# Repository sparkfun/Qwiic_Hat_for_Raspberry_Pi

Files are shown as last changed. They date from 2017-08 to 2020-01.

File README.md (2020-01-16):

SparkFun Qwiic pHAT v2.0 for Raspberry Pi
========================================

SparkFun Qwiic pHAT v2.0 for Raspberry Pi (https://www.sparkfun.com/products/15945)

[*SparkFun Qwiic pHAT for Raspberry Pi*](https://www.sparkfun.com/products/15945)

This is a board that connects the I<sup>2</sup>C bus on the Raspberry Pi to 4 Qwiic connectors.

Repository Contents
-------------------

* **/Hardware** - Eagle design files (.brd, .sch)
* **/Production** - Production panel files (.brd)

Documentation
--------------
* **[Hookup Guide](https://learn.sparkfun.com/tutorials/qwiic-phat-for-raspberry-pi-hookup-guide)** - Basic hookup guide for the SparkFun Qwiic pHAT for Raspberry Pi.

Product Versions
----------------
* [DEV-15945](https://www.sparkfun.com/products/15945)- Qwiic pHAT v2.0
* [DEV-15351](https://www.sparkfun.com/products/15351)- Qwiic pHAT v1.0
* [DEV-14459](https://www.sparkfun.com/products/14459) - Qwiic HAT SparkFun Reds Initial Release
* [DEV-14292](https://www.sparkfun.com/products/14292) - SparkX Version

License Information
-------------------

This product is _**open source**_! 

Please review the LICENSE.md file for license information. 

If you have any questions or concerns on licensing, please contact technical support on our [SparkFun forums](https://forum.sparkfun.com/viewforum.php?f=152).

Distributed as-is; no warranty is given.

- Your friends at SparkFun.

_<COLLABORATION CREDIT>_

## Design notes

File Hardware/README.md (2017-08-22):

SparkFun <PRODUCT NAME> Design Files
=====================================

The .sch and .brd files hare are Eagle CAD schematic and PCB design files from SparkFun Electronics.
A freeware version of Eagle can be found [here](http://www.cadsoftusa.com/download-eagle/freeware/).

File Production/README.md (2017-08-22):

SparkFun <PRODUCT NAME> Production Files
=========================================

These are the production files SparkFun uses for printing PCBs.

License Information
-------------------
This product is open source! 

The hardware is released under [Creative Commons ShareAlike 4.0 International](https://creativecommons.org/licenses/by-sa/4.0/).

Please use, reuse, and modify these files as you see fit. Please maintain attribution to SparkFun Electronics and release anything derivative under the same license.

Distributed as-is; no warranty is given.

- Your friends at SparkFun.

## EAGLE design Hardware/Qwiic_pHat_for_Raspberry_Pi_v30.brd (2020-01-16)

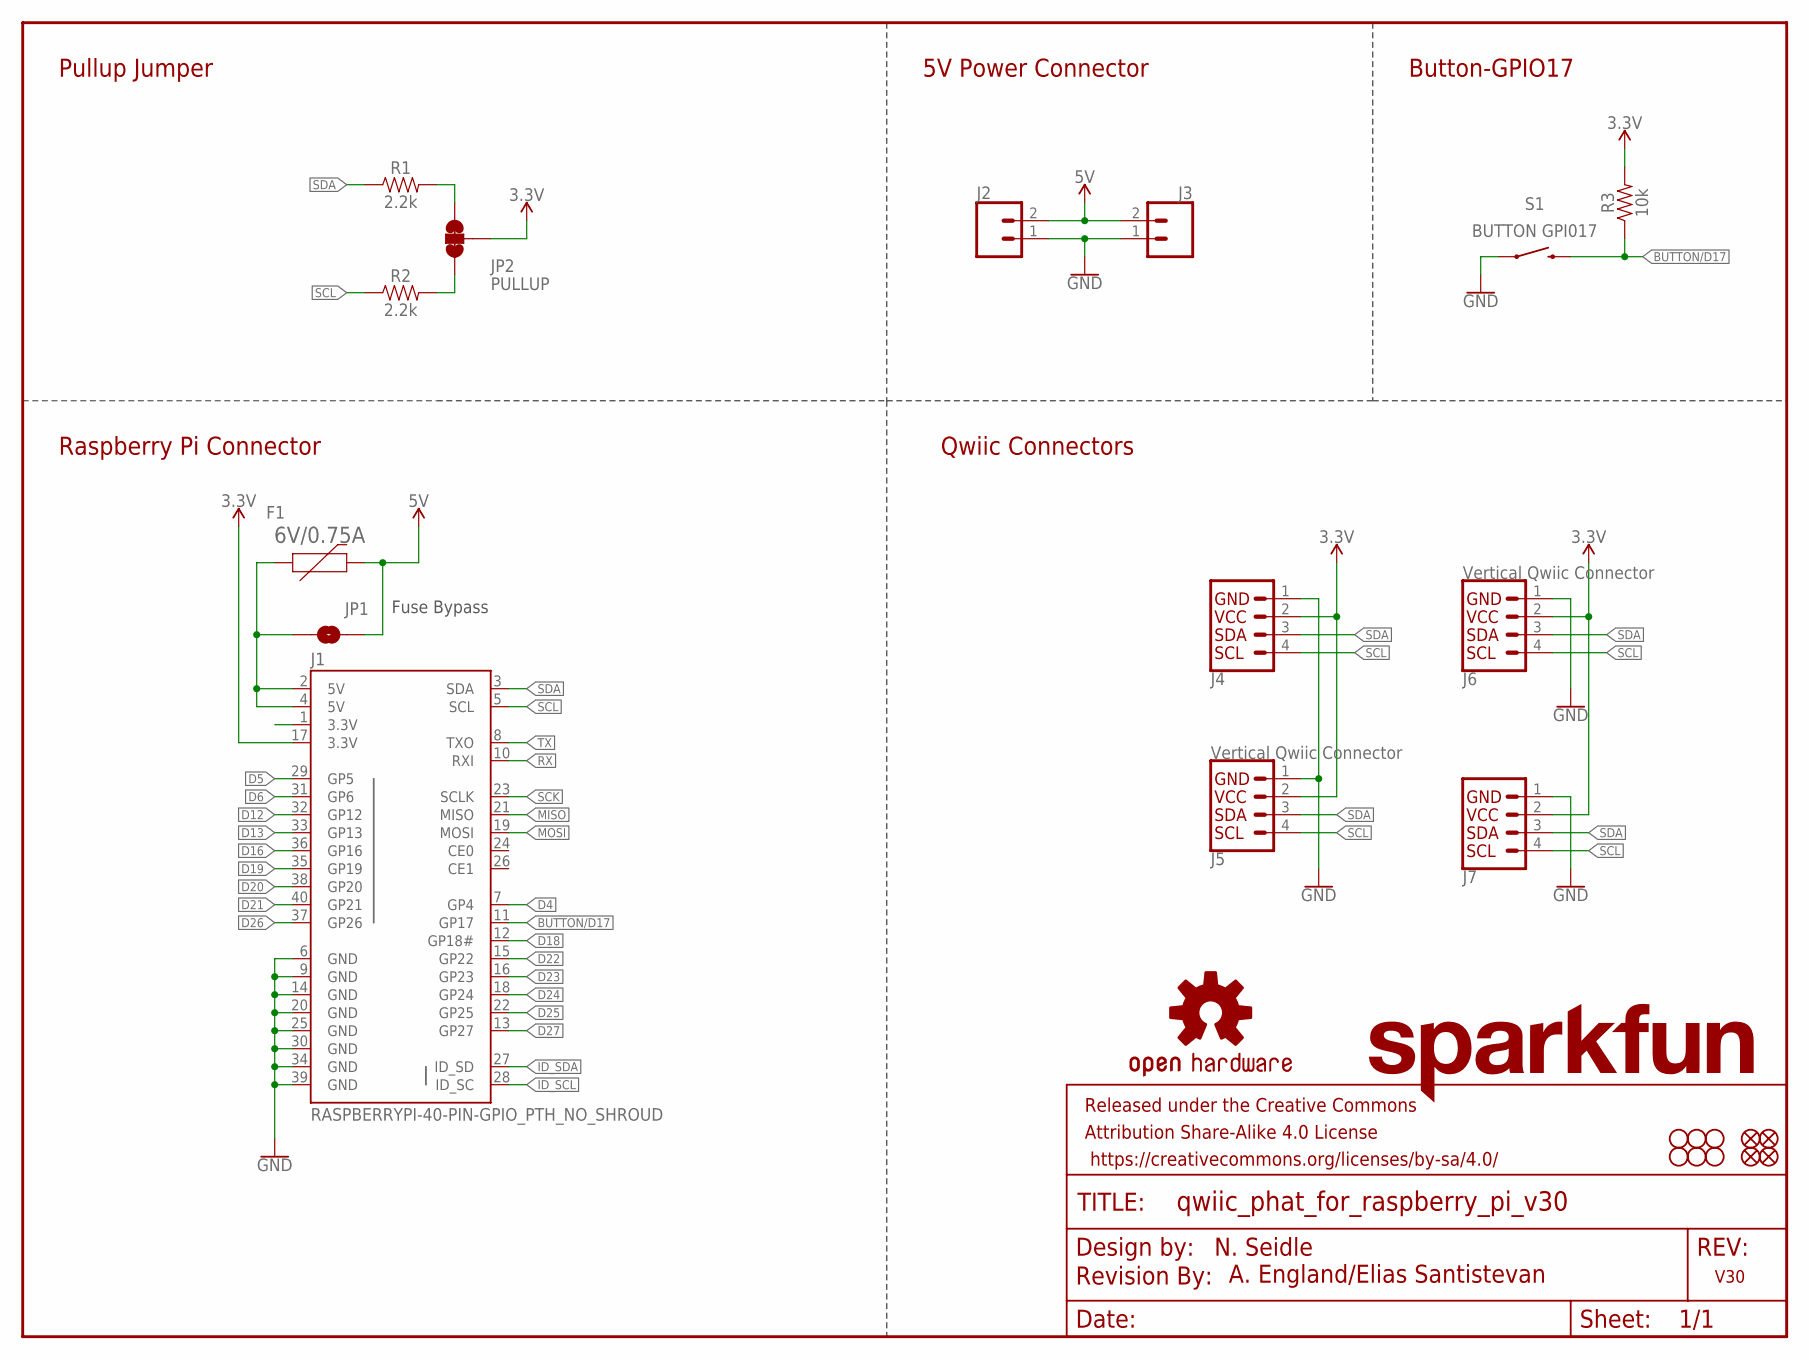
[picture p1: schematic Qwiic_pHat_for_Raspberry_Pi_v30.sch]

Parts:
F1: 6V/0.75A; 1206
FD1, FD2, FD3, FD4: FIDUCIAL1X2; FIDUCIAL-1X2
FRAME1: FRAME-LETTER; CREATIVE_COMMONS
H1, H2, H3, H4, H5, H6: STAND-OFFTIGHT; STAND-OFF-TIGHT
J1: RASPBERRYPI-40-PIN-GPIO_PTH_NO_SHROUD; 2X20
J2: CONN_023.5MM-NO_SILK; SCREWTERMINAL-3.5MM-2-NS
J3: CONN_023.5MM; SCREWTERMINAL-3.5MM-2
J4, J7: Qwiic Right Angle; JST04_1MM_RA
J5, J6: Vertical Qwiic Connector; JST04_1MM_VERT
JP1: JUMPER-SMT_2_NO_SILK; SMT-JUMPER_2_NO_SILK
JP2: PULLUP; SMT-JUMPER_3_2-NC_TRACE_NO-SILK
LOGO1: REVISION
LOGO2: OSHW-LOGOS; OSHW-LOGO-S
LOGO3: SFE_LOGO_NAME.1_INCH; SFE_LOGO_NAME_.1
R1, R2: 2.2k; 0603
R3: 10k; 0603
S1: BUTTON GPI017; TACTILE_SWITCH_SMD_5.2MM

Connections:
3.3V: J1.17 (3.3V), J4.2, J5.2, J6.2, J7.2, JP2.2, R3.2
5V: F1.2, J2.2, J3.2, JP1.2
BUTTON/D17: J1.11 (GP17), R3.1, S1.3 (2)
D4: J1.7 (GP4)
D5: J1.29 (GP5)
D6: J1.31 (GP6)
D12: J1.32 (GP12)
D13: J1.33 (GP13)
D16: J1.36 (GP16)
D18: J1.12 (GP18#)
D19: J1.35 (GP19)
D20: J1.38 (GP20)
D21: J1.40 (GP21)
D22: J1.15 (GP22)
D23: J1.16 (GP23)
D24: J1.18 (GP24)
D25: J1.22 (GP25)
D26: J1.37 (GP26)
D27: J1.13 (GP27)
GND: J1.6 (GND), J1.9 (GND), J1.14 (GND), J1.20 (GND), J1.25 (GND), J1.30 (GND), J1.34 (GND), J1.39 (GND), J2.1, J3.1, J4.1, J5.1, J6.1, J7.1, S1.1
ID_SCL: J1.28 (ID_SC)
ID_SDA: J1.27 (ID_SD)
MISO: J1.21 (MISO)
MOSI: J1.19 (MOSI)
unnamed: F1.1, J1.2 (5V), J1.4 (5V), JP1.1
unnamed: JP2.3, R1.2
unnamed: JP2.1, R2.2
RX: J1.10 (RXI)
SCK: J1.23 (SCLK)
SCL: J1.5 (SCL), J4.4, J5.4, J6.4, J7.4, R2.1
SDA: J1.3 (SDA), J4.3, J5.3, J6.3, J7.3, R1.1
TX: J1.8 (TXO)

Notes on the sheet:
N. Seidle
Raspberry Pi Connector
V30
Qwiic Connectors
A. England/Elias Santistevan
Pullup Jumper
5V Power Connector
Button-GPIO17
Fuse Bypass

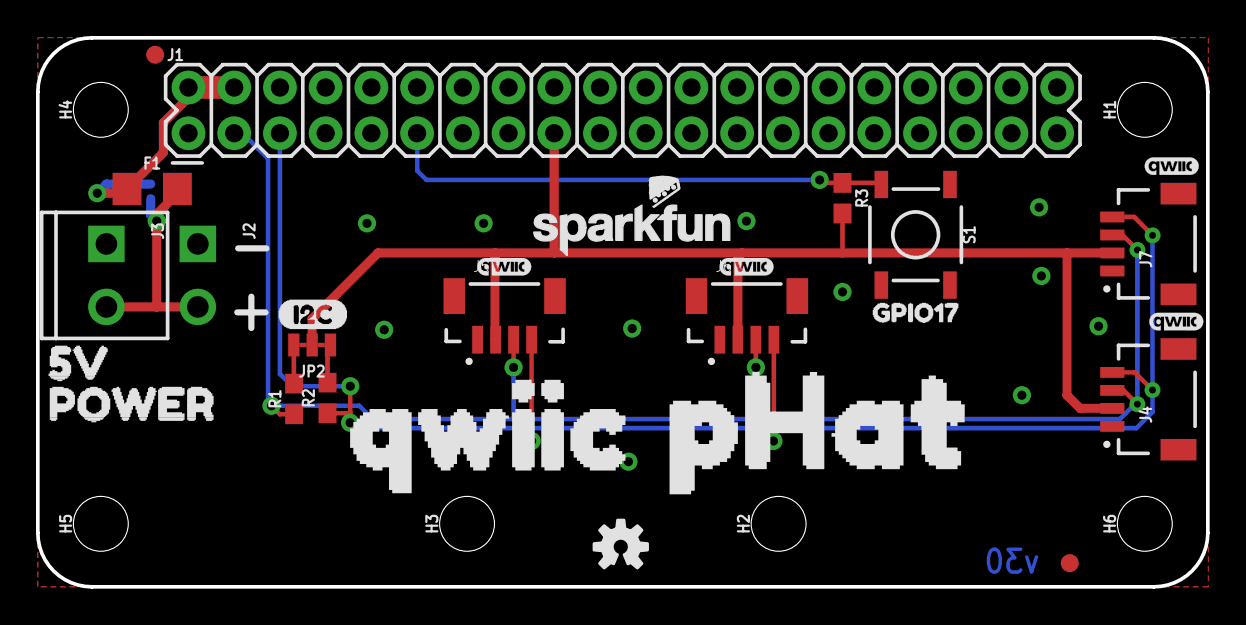
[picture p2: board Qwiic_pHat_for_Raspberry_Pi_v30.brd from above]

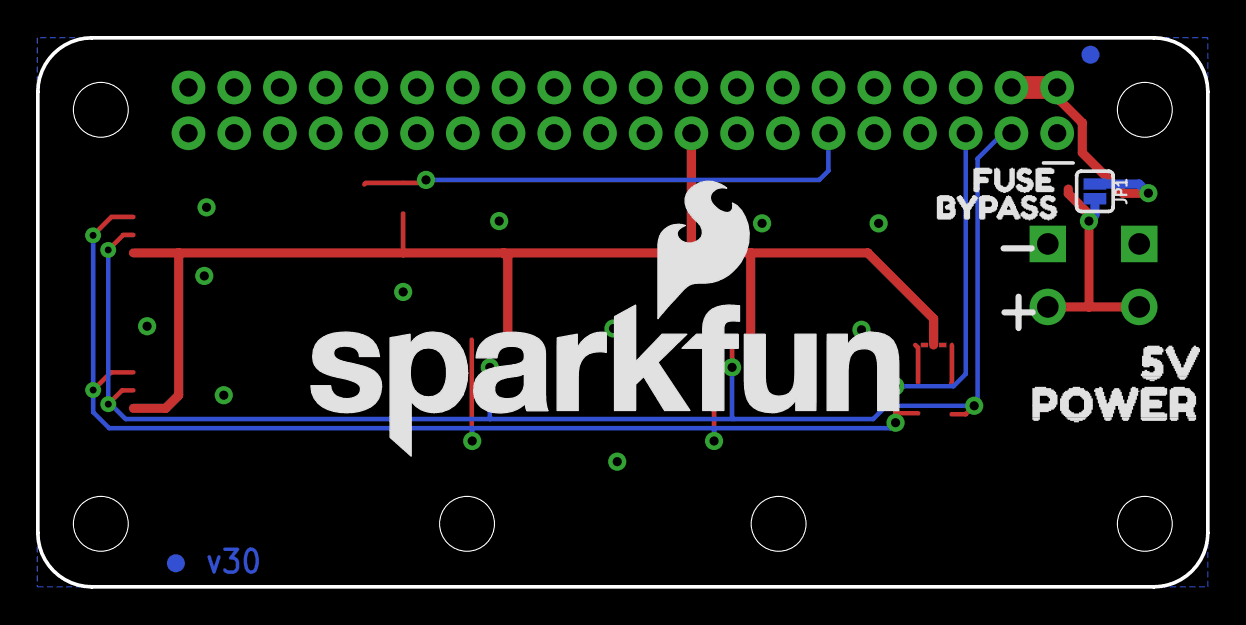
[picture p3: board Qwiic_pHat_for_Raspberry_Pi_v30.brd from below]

Board: 2 copper layers, 65.0 x 30.5 mm, 44 parts (8 on the bottom side), 9 nets.

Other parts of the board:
U$1: PIE_1F967#PNG
U$2: I2C-()
U$3: PHAT0
U$6: FUSE0
U$7: BYPASS1
U$8, U$11, U$16, U$17: QWIIC_3MM
U$9: GPIO173
U$10: SFE_LOGO_NAME_FLAME_.3
U$12, U$15: 5V0
U$13, U$14: POWER1
U$18: QWIIC0

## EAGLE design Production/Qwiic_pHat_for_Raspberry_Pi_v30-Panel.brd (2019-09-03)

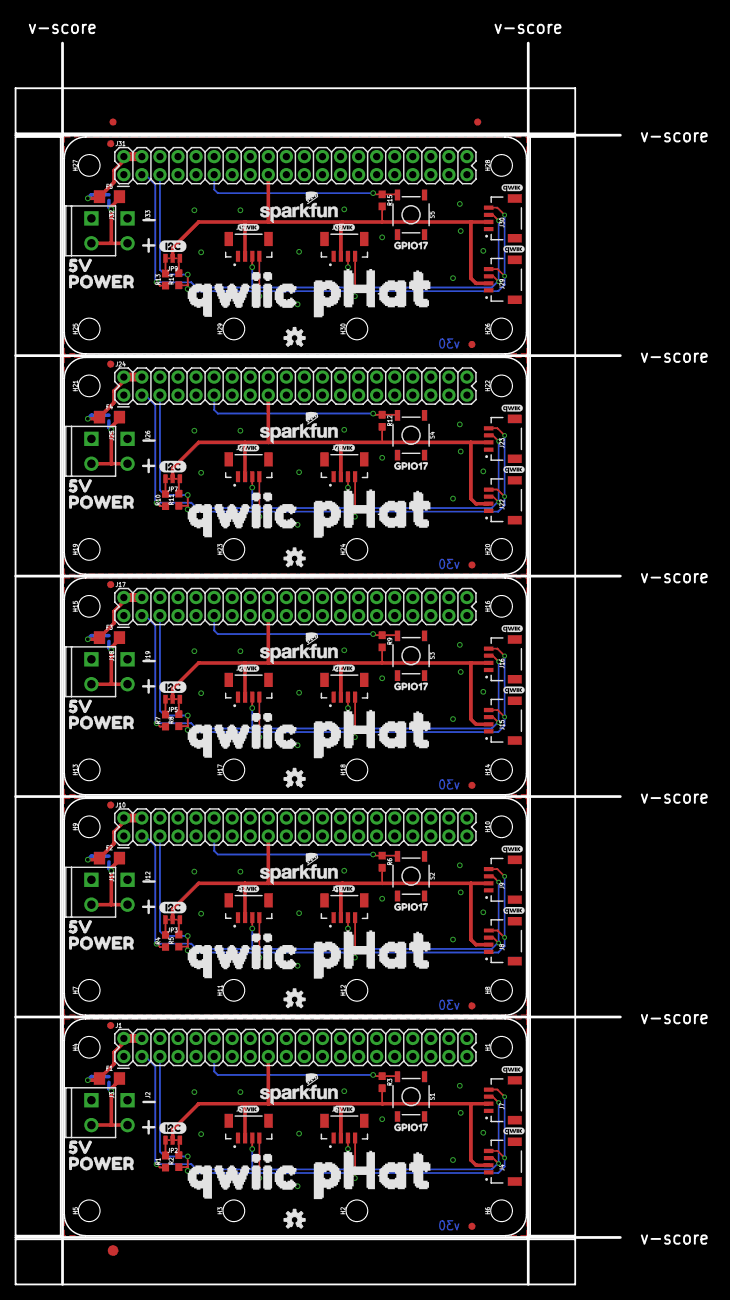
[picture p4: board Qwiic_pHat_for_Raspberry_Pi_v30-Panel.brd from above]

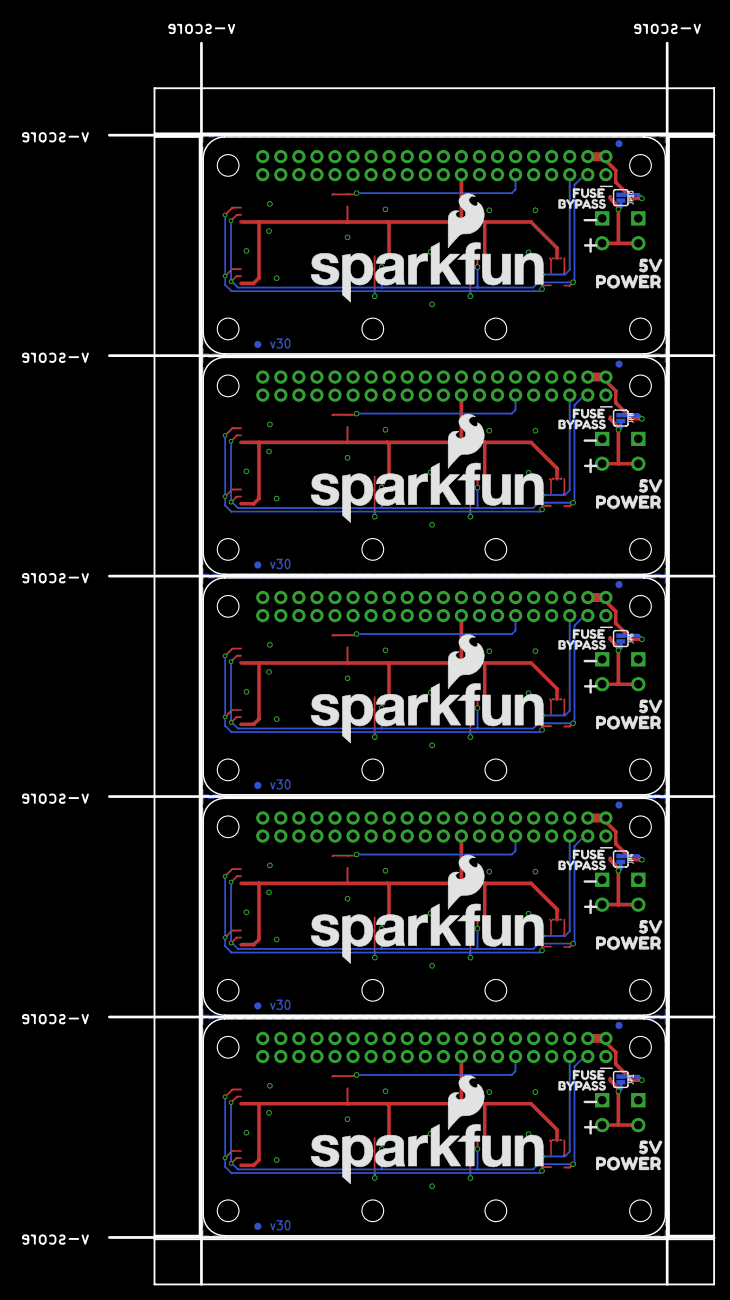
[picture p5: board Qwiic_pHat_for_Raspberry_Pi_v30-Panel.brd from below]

Board: 2 copper layers, 85.1 x 174.6 mm, 223 parts (40 on the bottom side), 45 nets.

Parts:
E$1, E$2: FIDUCIAL-1X2
E$3: FIDUCIAL-1.5X3
F1, F2, F3, F4, F5: 6V/0.75A; 1206
FD1, FD2, FD3, FD4, FD5, FD6, FD7, FD8, FD9, FD10, FD11, FD12, FD13, FD14, FD15, FD16, FD17, FD18, FD19, FD20: FIDUCIAL1X2; FIDUCIAL-1X2
FRAME1, FRAME2, FRAME3, FRAME4, FRAME5: FRAME-LETTER; CREATIVE_COMMONS
H1, H2, H3, H4, H5, H6, H7, H8, H9, H10, H11, H12, H13, H14, H15, H16, H17, H18, H19, H20, H21, H22, H23, H24, H25, H26, H27, H28, H29, H30: STAND-OFFTIGHT; STAND-OFF-TIGHT
J1, J10, J17, J24, J31: RASPBERRYPI-40-PIN-GPIO_PTH_NO_SHROUD; 2X20
J2, J12, J19, J26, J33: SCREWTERMINAL-3.5MM-2-NS
J3, J11, J18, J25, J32: SCREWTERMINAL-3.5MM-2
J4, J7, J8, J9, J15, J16, J22, J23, J29, J30: Qwiic Right Angle; JST04_1MM_RA
J5, J6, J13, J14, J20, J21, J27, J28, J34, J35: Vertical Qwiic Connector; JST04_1MM_VERT
JP1, JP4, JP6, JP8, JP10: JUMPER-SMT_2_NO_SILK; SMT-JUMPER_2_NO_SILK
JP2, JP3, JP5, JP7, JP9: PULLUP; SMT-JUMPER_3_2-NC_TRACE_NO-SILK
LOGO1, LOGO4, LOGO7, LOGO10, LOGO13: REVISION
LOGO2, LOGO5, LOGO8, LOGO11, LOGO14: OSHW-LOGOS; OSHW-LOGO-S
LOGO3, LOGO6, LOGO9, LOGO12, LOGO15: SFE_LOGO_NAME.1_INCH; SFE_LOGO_NAME_.1
R1, R2, R4, R5, R7, R8, R10, R11, R13, R14: 2.2k; 0603
R3, R6, R9, R12, R15: 10k; 0603
S1, S2, S3, S4, S5: BUTTON GPI017; TACTILE_SWITCH_SMD_5.2MM
U$1, U$31, U$47, U$63, U$79: PIE_1F967#PNG
U$2, U$5, U$34, U$50, U$66: I2C-()
U$3, U$4, U$33, U$49, U$65: PHAT0
U$6, U$20, U$36, U$52, U$68: FUSE0
U$7, U$21, U$37, U$53, U$69: BYPASS1
U$8, U$11, U$16, U$17, U$22, U$27, U$28, U$29, U$38, U$43, U$44, U$45, U$54, U$59, U$60, U$61, U$70, U$75, U$76, U$77: QWIIC_3MM
U$9, U$19, U$35, U$51, U$67: GPIO173
U$10, U$32, U$48, U$64, U$80: SFE_LOGO_NAME_FLAME_.3
U$12, U$15, U$23, U$26, U$39, U$42, U$55, U$58, U$71, U$74: 5V0
U$13, U$14, U$24, U$25, U$40, U$41, U$56, U$57, U$72, U$73: POWER1
U$18, U$30, U$46, U$62, U$78: QWIIC0

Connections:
3.3V: J1.17, J4.2, J5.2, J6.2, J7.2, JP2.2, R3.2
3.3V1: J8.2, J9.2, J10.17, J13.2, J14.2, JP3.2, R6.2
3.3V2: J15.2, J16.2, J17.17, J20.2, J21.2, JP5.2, R9.2
3.3V3: J22.2, J23.2, J24.17, J27.2, J28.2, JP7.2, R12.2
3.3V4: J29.2, J30.2, J31.17, J34.2, J35.2, JP9.2, R15.2
5V: F1.2, J2.2, J3.2, JP1.2
5V1: F2.2, J11.2, J12.2, JP4.2
5V2: F3.2, J18.2, J19.2, JP6.2
5V3: F4.2, J25.2, J26.2, JP8.2
5V4: F5.2, J32.2, J33.2, JP10.2
BUTTON/D1: J10.11, R6.1, S2.3
BUTTON/D2: J17.11, R9.1, S3.3
BUTTON/D3: J24.11, R12.1, S4.3
BUTTON/D4: J31.11, R15.1, S5.3
BUTTON/D17: J1.11, R3.1, S1.3
GND: J1.6, J1.9, J1.14, J1.20, J1.25, J1.30, J1.34, J1.39, J2.1, J3.1, J4.1, J5.1, J6.1, J7.1, S1.1
GND1: J8.1, J9.1, J10.6, J10.9, J10.14, J10.20, J10.25, J10.30, J10.34, J10.39, J11.1, J12.1, J13.1, J14.1, S2.1
GND2: J15.1, J16.1, J17.6, J17.9, J17.14, J17.20, J17.25, J17.30, J17.34, J17.39, J18.1, J19.1, J20.1, J21.1, S3.1
GND3: J22.1, J23.1, J24.6, J24.9, J24.14, J24.20, J24.25, J24.30, J24.34, J24.39, J25.1, J26.1, J27.1, J28.1, S4.1
GND4: J29.1, J30.1, J31.6, J31.9, J31.14, J31.20, J31.25, J31.30, J31.34, J31.39, J32.1, J33.1, J34.1, J35.1, S5.1
unnamed: F1.1, J1.2, J1.4, JP1.1
unnamed: JP2.3, R1.2
unnamed: JP2.1, R2.2
unnamed: JP3.3, R4.2
unnamed: JP3.1, R5.2
unnamed: F2.1, J10.2, J10.4, JP4.1
unnamed: JP5.3, R7.2
unnamed: JP5.1, R8.2
unnamed: F3.1, J17.2, J17.4, JP6.1
unnamed: JP7.3, R10.2
unnamed: JP7.1, R11.2
unnamed: F4.1, J24.2, J24.4, JP8.1
unnamed: JP9.3, R13.2
unnamed: JP9.1, R14.2
unnamed: F5.1, J31.2, J31.4, JP10.1
SCL: J1.5, J4.4, J5.4, J6.4, J7.4, R2.1
SCL1: J8.4, J9.4, J10.5, J13.4, J14.4, R5.1
SCL2: J15.4, J16.4, J17.5, J20.4, J21.4, R8.1
SCL3: J22.4, J23.4, J24.5, J27.4, J28.4, R11.1
SCL4: J29.4, J30.4, J31.5, J34.4, J35.4, R14.1
SDA: J1.3, J4.3, J5.3, J6.3, J7.3, R1.1
SDA1: J8.3, J9.3, J10.3, J13.3, J14.3, R4.1
SDA2: J15.3, J16.3, J17.3, J20.3, J21.3, R7.1
SDA3: J22.3, J23.3, J24.3, J27.3, J28.3, R10.1
SDA4: J29.3, J30.3, J31.3, J34.3, J35.3, R13.1

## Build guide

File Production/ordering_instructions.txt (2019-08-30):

panel size, 79x169mm
PCB thickness, 1.6mm
number of layers, 2
soldermask color, Red
silkscreen color, White
oz copper, 1oz
finish, HASL lead free
stencils, top+bottom
pcs per panel, 5
min trace width, 0.254000mm / 0.010000in
min drill size, 0.381000mm / 0.015000in

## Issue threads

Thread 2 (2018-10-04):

Consider I2C Pullups

nseidle, 2018-10-04:
We may want to add 2.2k pull ups with a I2C cut away jumper on the next rev.

edspark, 2019-04-26:
Each of our daughter boards have pull ups, do you still think this is necessary still? I suppose it wouldn't hurt....

edspark, 2019-04-26:
Added to v20

Closed 2019-04-26.

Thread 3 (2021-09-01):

Using pHAT on a different I2C bus

tamugo, 2021-09-01:
I'm working on a project where I am making use of a BME680 and IMU 20948 connected to a Raspberry Pi Zero using the Qwiic pHAT v2.0. I also have a battery pack that connects to the RPi the gpio pins. The pins on the battery's distribution board are connected to the first I2C bus, and so I want to make a second I2C bus and have the BME680 and IMU-20948 route through the new bus, but when I do the second bus shows no active addresses. Is there a way to have them go through a new I2C bus?

Closed 2021-09-01.

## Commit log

2017-08-23 Engineering checklist changes
    [Board_Design_Checklist.xls, Board_Design_Checklist_Qwiic Shield for Raspberry Pi_V01.xls, Qwiic Shield for RaspberryPi.brd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]
2017-08-25 Post design review changes
    [Qwiic Shield for RaspberryPi.brd]
2017-09-28 post design review
    [Board_Design_Checklist_Qwiic Shield for Raspberry Pi_V01.xls, Qwiic Shield for RaspberryPi.brd, Qwiic Shield for RaspberryPi.sch]
2017-09-28 Updated PROD_ID of 2x20
    [Qwiic Shield for RaspberryPi.brd, Qwiic Shield for RaspberryPi.sch]
2019-05-21 Update File Names
    Update file names to be consistent with name and version
    [Qwiic_pHat_for_Raspberry_Pi_v20.brd, Qwiic_pHat_for_Raspberry_Pi_v20.sch]
2019-05-21 Undo renaming
    [Qwiic Shield for RaspberryPi.brd, Qwiic Shield for RaspberryPi.sch]
2019-07-19 Removes production old files from v30
    [13791-Qwiic Shield for RaspberryPi-panel.v10.brd, Qwiic Shield for RaspberryPi.brd, Qwiic Shield for RaspberryPi.sch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]
2019-07-19 Renames board files to v30 for clarity
    [Qwiic_pHat_for_Raspberry_Pi_v30.brd, Qwiic_pHat_for_Raspberry_Pi_v30.sch]
2019-07-19 Adds vertical Qwiic connectors to board
    [Qwiic_pHat_for_Raspberry_Pi_v30.brd, Qwiic_pHat_for_Raspberry_Pi_v30.sch]
2019-07-22 Updates vertical qwiic connector footprint, recenters vertical qwiic connector.
    [Qwiic_pHat_for_Raspberry_Pi_v30.brd, Qwiic_pHat_for_Raspberry_Pi_v30.sch]
2019-07-23 Changes button and 5V power labels to text only, changes button text to "button" with gpio number
    * Adds parallel 5V power through holes
    * moves + and - silk
    * moves button gpio pin to 17
    [Qwiic_pHat_for_Raspberry_Pi_v30.brd, Qwiic_pHat_for_Raspberry_Pi_v30.sch]
2019-07-23 Adds gerbers
    [Qwiic_pHat_for_Raspberry_Pi_v30.GBL, Qwiic_pHat_for_Raspberry_Pi_v30.GBO, Qwiic_pHat_for_Raspberry_Pi_v30.GBS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]
2019-07-24 Adjusts 5V Power silk, changes button name in schematic
    [Qwiic_pHat_for_Raspberry_Pi_v30.brd, Qwiic_pHat_for_Raspberry_Pi_v30.sch]
2019-08-27 Adds resettable 750mA fuse to 5V power line
    [Qwiic_pHat_for_Raspberry_Pi_v30.brd, Qwiic_pHat_for_Raspberry_Pi_v30.sch]
2019-08-27 Moves 5V screw terminal and pull up resistors away from each other
    [Qwiic_pHat_for_Raspberry_Pi_v30.brd]
2019-08-28 Updates the silk
    [Qwiic_pHat_for_Raspberry_Pi_v30.brd, Qwiic_pHat_for_Raspberry_Pi_v30.sch]
2019-08-29 Swaps power and ground on screw terminal, adjusts silk in various areas
    [Qwiic_pHat_for_Raspberry_Pi_v30.brd, Qwiic_pHat_for_Raspberry_Pi_v30.sch]
2019-08-30 Updates vertical qwiic connector footprint
    [Qwiic_pHat_for_Raspberry_Pi_v30.brd]
2019-08-30 Adds current production files
    [Qwiic_pHat_for_Raspberry_Pi_v30-Panel.GBL, Qwiic_pHat_for_Raspberry_Pi_v30-Panel.GBO, Qwiic_pHat_for_Raspberry_Pi_v30-Panel.GBS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]
2019-09-03 Fixes vertical qwiic connector polarity marker with updated package, removes Qwiic board reference on TDocu
    [Qwiic_pHat_for_Raspberry_Pi_v30.brd, Qwiic_pHat_for_Raspberry_Pi_v30.sch]
2019-09-03 Updates Vertical Qwiic connector to have value of "vertical qwiic connector"
    [Qwiic_pHat_for_Raspberry_Pi_v30.brd, Qwiic_pHat_for_Raspberry_Pi_v30.sch]
2019-09-03 Nudges via on SparkFun flame
    [Qwiic_pHat_for_Raspberry_Pi_v30.brd]
2019-09-03 Adds updated production panel
    [Qwiic_pHat_for_Raspberry_Pi_v30-Panel.GBL, Qwiic_pHat_for_Raspberry_Pi_v30-Panel.GBO, Qwiic_pHat_for_Raspberry_Pi_v30-Panel.GBS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]
2020-01-16 Update Qwiic_pHat_for_Raspberry_Pi_v30.brd
    - Adjust Measures Layer for Board/Mounting Hole Dimensions
    - Make Text Ratio the Uniform for Measures
    - Move Aesthetics Down to Read Measures Layer
    [Qwiic_pHat_for_Raspberry_Pi_v30.brd]

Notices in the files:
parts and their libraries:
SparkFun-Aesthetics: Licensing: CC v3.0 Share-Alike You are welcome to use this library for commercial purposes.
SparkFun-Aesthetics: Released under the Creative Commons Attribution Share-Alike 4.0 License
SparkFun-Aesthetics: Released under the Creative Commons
